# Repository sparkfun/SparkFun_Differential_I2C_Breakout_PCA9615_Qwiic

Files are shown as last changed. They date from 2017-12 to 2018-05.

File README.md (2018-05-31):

SparkFun Differential I2C Breakout - PCA9615 (Qwiic)
========================================

SparkFun Differential I2C Breakout - PCA9615 (Qwiic) (https://cdn.sparkfun.com/assets/parts/1/2/7/4/5/14589-SparkFun_Differential_I2C_Breakout_-_PCA9615__Qwiic_-01.jpg)

[*SparkFun Differential I2C Breakout - PCA9615 (Qwiic) (BOB-14589)*](https://www.sparkfun.com/products/14589)

The SparkFun Differential I<sup>2</sup>C Breakout is the fastest and easiest way to extend the range of your I<sup>2</sup>C communication bus. The breakout uses NXP’s PCA9615 IC, which converts the two default I<sup>2</sup>C signals into four differential signals, two for SCL and two for SDA. 

Repository Contents
-------------------

* **/Documentation** - Datasheets, additional product information
* **/Hardware** - Eagle design files (.brd, .sch)
* **/Production** - Production panel files (.brd)

Documentation
--------------
* **[Hookup Guide](https://learn.sparkfun.com/tutorials/qwiic-differential-i2c-bus-extender-pca9615-hookup-guide)** - Basic hookup guide for the SparkFun Differential I2C Breakout - PCA9615 (Qwiic).

Product Versions
----------------
* [BOB-14589](https://www.sparkfun.com/products/14589)

License Information
-------------------

This product is _**open source**_! 

Please review the LICENSE.md file for license information. 

If you have any questions or concerns on licensing, please contact techsupport@sparkfun.com.

Distributed as-is; no warranty is given.

- Your friends at SparkFun.

_<COLLABORATION CREDIT>_

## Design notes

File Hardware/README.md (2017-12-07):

SparkFun <PRODUCT NAME> Design Files
=====================================

The .sch and .brd files hare are Eagle CAD schematic and PCB design files from SparkFun Electronics.
A freeware version of Eagle can be found [here](http://www.cadsoftusa.com/download-eagle/freeware/).

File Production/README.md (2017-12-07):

SparkFun <PRODUCT NAME> Production Files
=========================================

These are the production files SparkFun uses for printing PCBs.

License Information
-------------------
This product is open source! 

The hardware is released under [Creative Commons ShareAlike 4.0 International](https://creativecommons.org/licenses/by-sa/4.0/).

Please use, reuse, and modify these files as you see fit. Please maintain attribution to SparkFun Electronics and release anything derivative under the same license.

Distributed as-is; no warranty is given.

- Your friends at SparkFun.

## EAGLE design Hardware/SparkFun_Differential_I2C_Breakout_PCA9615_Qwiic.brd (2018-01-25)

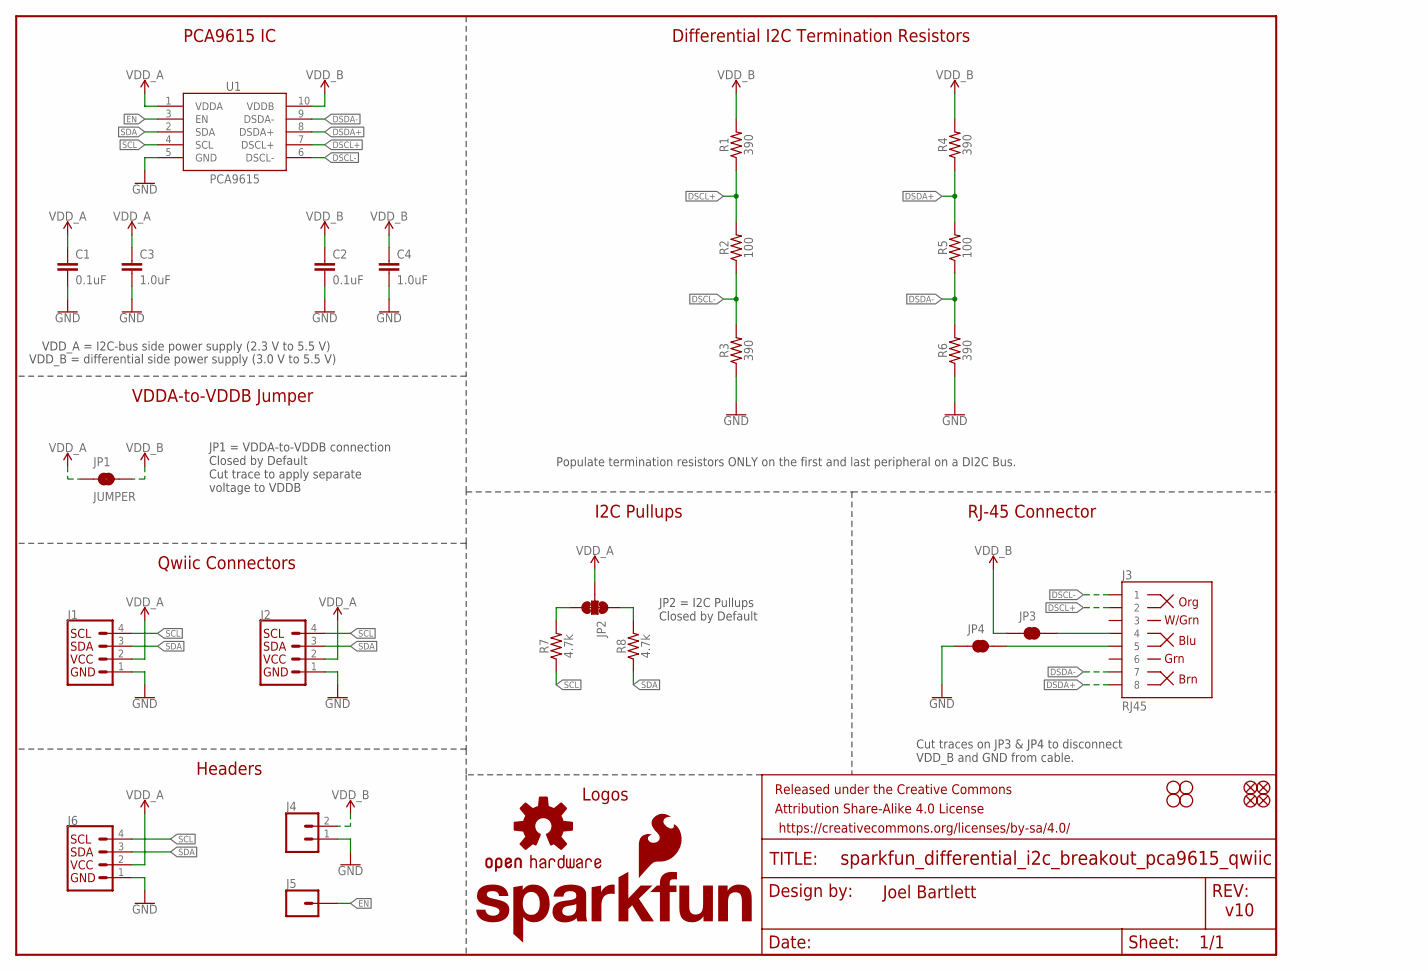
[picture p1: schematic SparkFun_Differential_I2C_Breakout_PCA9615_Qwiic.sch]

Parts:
C1, C2: 0.1uF; 0603
C3, C4: 1.0uF; 0603
FD1, FD2, FD3, FD4: FIDUCIALUFIDUCIAL; FIDUCIAL-MICRO
FRAME1: FRAME-LETTER; CREATIVE_COMMONS
H1, H2, H3, H4: STAND-OFF
J1, J2: QWIIC_CONNECTORJS-1MM; 1X04_1MM_RA
J3: RJ45; RJ45-8
J4: CONN_021X02_NO_SILK; 1X02_NO_SILK
J5: CONN_01PTH_NO_SILK_YES_STOP; 1X01_NO_SILK
J6: I2C_STANDARD_NO_SILK; 1X04_NO_SILK
JP1: JUMPER; SMT-JUMPER_2_NC_TRACE_SILK
JP2: JUMPER-SMT_3_2-NC_TRACE_SILK; SMT-JUMPER_3_2-NC_TRACE_SILK
JP3, JP4: JUMPER-SMT_2_NC_TRACE_SILK; SMT-JUMPER_2_NC_TRACE_SILK
LOGO1: OSHW-LOGOM; OSHW-LOGO-M
LOGO5: SFE_LOGO_NAME_FLAME.1_INCH; SFE_LOGO_NAME_FLAME_.1
R1, R3, R4, R6: 390; 0603
R2, R5: 100; 0603
R7, R8: 4.7k; 0603
U1: PCA9615; TSSOP10

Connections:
DSCL+: J3.2, R1.1, R2.2, U1.7 (DSCL+)
DSCL-: J3.1, R2.1, R3.2, U1.6 (DSCL-)
DSDA+: J3.8, R4.1, R5.2, U1.8 (DSDA+)
DSDA-: J3.7, R5.1, R6.2, U1.9 (DSDA-)
EN: J5.1, U1.3 (EN)
GND: C1.2, C2.2, C3.2, C4.2, J1.1, J2.1, J4.1, J6.1 (GND), JP4.1, R3.1, R6.1, U1.5 (GND)
unnamed: J3.4, JP3.2
unnamed: J3.5, JP4.2
unnamed: JP2.1, R8.2
unnamed: JP2.3, R7.2
SCL: J1.4, J2.4, J6.4 (SCL), R7.1, U1.4 (SCL)
SDA: J1.3, J2.3, J6.3 (SDA), R8.1, U1.2 (SDA)
VDD_A: C1.1, C3.1, J1.2, J2.2, J6.2 (VCC), JP1.1, JP2.2, U1.1 (VDDA)
VDD_B: C2.1, C4.1, J4.2, JP1.2, JP3.1, R1.2, R4.2, U1.10 (VDDB)

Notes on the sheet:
Joel Bartlett
VDDA-to-VDDB Jumper
PCA9615 IC
Qwiic Connectors
v10
JP2 = I2C Pullups Closed by Default
Headers
JP1 = VDDA-to-VDDB connection Closed by Default Cut trace to apply separate voltage to VDDB
I2C Pullups
RJ-45 Connector
Logos
Differential I2C Termination Resistors
Populate termination resistors ONLY on the first and last peripheral on a DI2C Bus.
VDD_A = I2C-bus side power supply (2.3 V to 5.5 V)
VDD_B = differential side power supply (3.0 V to 5.5 V)
Cut traces on JP3 & JP4 to disconnect VDD_B and GND from cable.

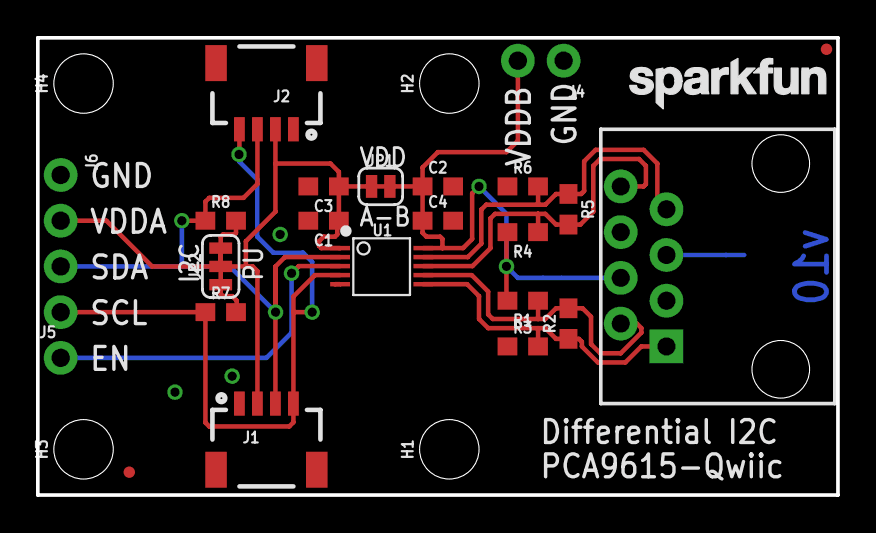
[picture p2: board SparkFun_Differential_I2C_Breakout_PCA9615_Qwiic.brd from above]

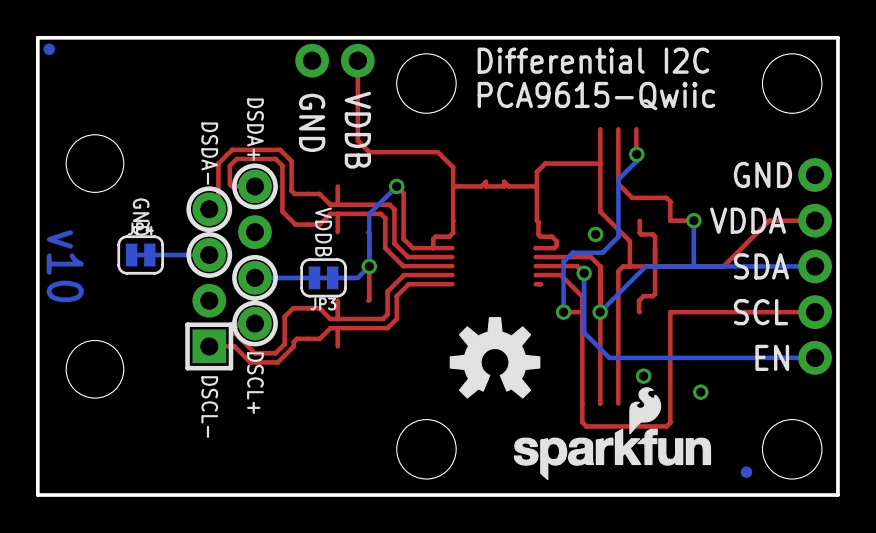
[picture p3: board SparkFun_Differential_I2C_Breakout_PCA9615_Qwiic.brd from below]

Board: 2 copper layers, 44.5 x 25.4 mm, 35 parts (6 on the bottom side), 14 nets.

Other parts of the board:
LOGO3: SFE_LOGO_NAME.1_INCH; SFE_LOGO_NAME_.1

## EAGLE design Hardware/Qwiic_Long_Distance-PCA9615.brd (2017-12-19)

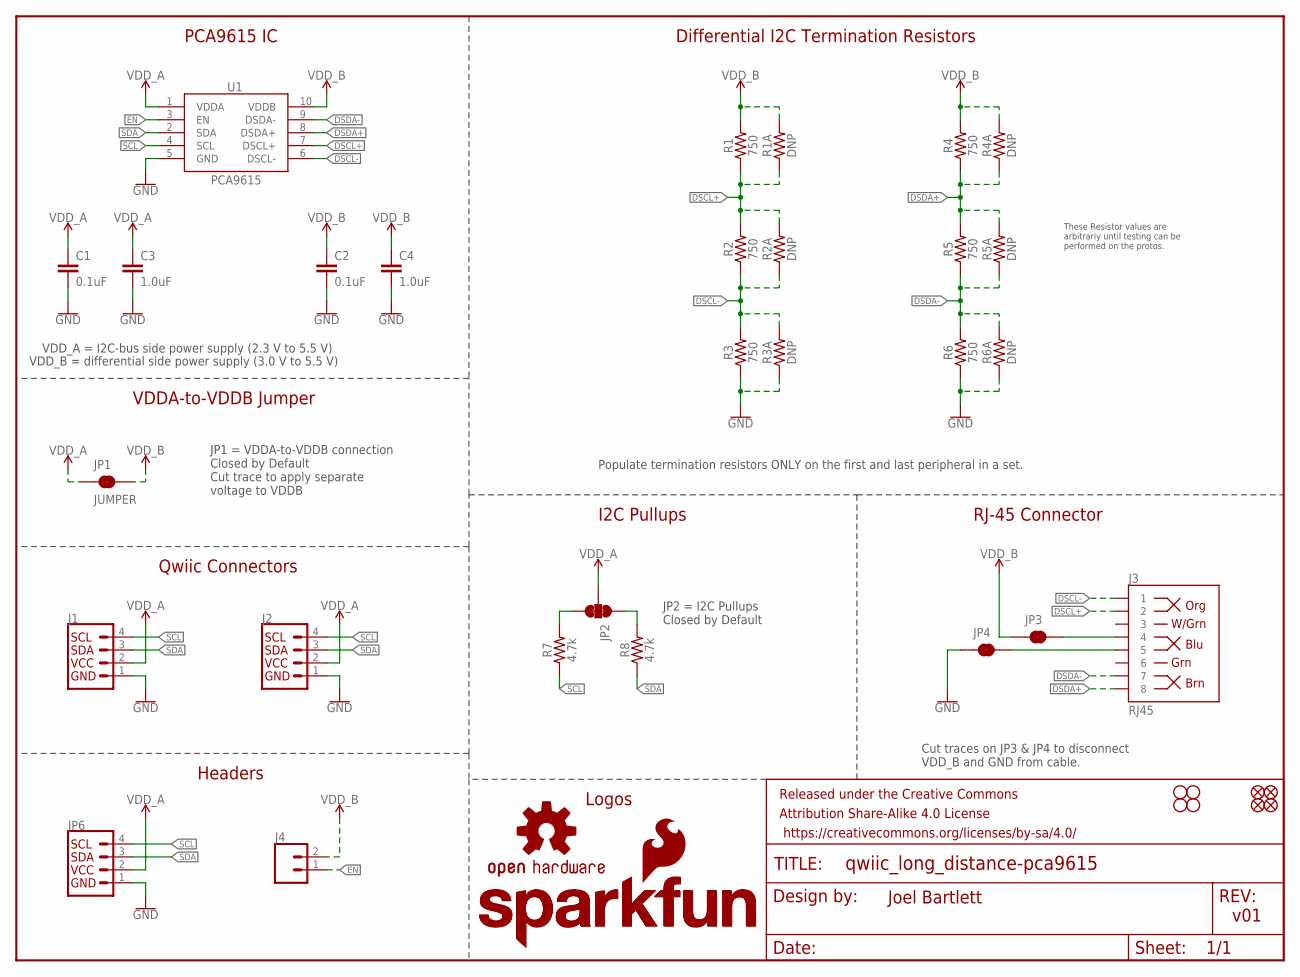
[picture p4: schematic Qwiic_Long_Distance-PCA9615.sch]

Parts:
C1, C2: 0.1uF; 0603
C3, C4: 1.0uF; 0603
FD1, FD2, FD3, FD4: FIDUCIALUFIDUCIAL; FIDUCIAL-MICRO
FRAME1: FRAME-LETTER; CREATIVE_COMMONS
H1, H2, H3, H4: STAND-OFF
J1, J2: QWIIC_CONNECTORJS-1MM; 1X04_1MM_RA
J3: RJ45; RJ45-8
J4: CONN_02; 1X02
JP1: JUMPER; SMT-JUMPER_2_NC_TRACE_SILK
JP2: JUMPER-SMT_3_2-NC_TRACE_SILK; SMT-JUMPER_3_2-NC_TRACE_SILK
JP3, JP4: JUMPER-SMT_2_NC_TRACE_SILK; SMT-JUMPER_2_NC_TRACE_SILK
JP6: I2C_STANDARDSILK; 1X04
LOGO1: OSHW-LOGOM; OSHW-LOGO-M
LOGO2: SFE_LOGO_NAME.1_INCH; SFE_LOGO_NAME_.1
LOGO5: SFE_LOGO_NAME_FLAME.1_INCH; SFE_LOGO_NAME_FLAME_.1
R1, R2, R3, R4, R5, R6: 750; 0603
R1A, R2A, R3A, R4A, R5A, R6A: DNP; AXIAL-0.3
R7, R8: 4.7k; 0603
U1: PCA9615; TSSOP10

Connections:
DSCL+: J3.2, R1.1, R1A.P$1 (1), R2.2, R2A.P$2 (2), U1.7 (DSCL+)
DSCL-: J3.1, R2.1, R2A.P$1 (1), R3.2, R3A.P$2 (2), U1.6 (DSCL-)
DSDA+: J3.8, R4.1, R4A.P$1 (1), R5.2, R5A.P$2 (2), U1.8 (DSDA+)
DSDA-: J3.7, R5.1, R5A.P$1 (1), R6.2, R6A.P$2 (2), U1.9 (DSDA-)
EN: J4.1, U1.3 (EN)
GND: C1.2, C2.2, C3.2, C4.2, J1.1, J2.1, JP4.1, JP6.1 (GND), R3.1, R3A.P$1 (1), R6.1, R6A.P$1 (1), U1.5 (GND)
unnamed: J3.4, JP3.2
unnamed: J3.5, JP4.2
unnamed: JP2.1, R8.2
unnamed: JP2.3, R7.2
SCL: J1.4, J2.4, JP6.4 (SCL), R7.1, U1.4 (SCL)
SDA: J1.3, J2.3, JP6.3 (SDA), R8.1, U1.2 (SDA)
VDD_A: C1.1, C3.1, J1.2, J2.2, JP1.1, JP2.2, JP6.2 (VCC), U1.1 (VDDA)
VDD_B: C2.1, C4.1, J4.2, JP1.2, JP3.1, R1.2, R1A.P$2 (2), R4.2, R4A.P$2 (2), U1.10 (VDDB)

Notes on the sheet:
Joel Bartlett
VDDA-to-VDDB Jumper
PCA9615 IC
Qwiic Connectors
v01
JP2 = I2C Pullups Closed by Default
Headers
JP1 = VDDA-to-VDDB connection Closed by Default Cut trace to apply separate voltage to VDDB
I2C Pullups
RJ-45 Connector
Logos
Differential I2C Termination Resistors
Populate termination resistors ONLY on the first and last peripheral in a set.
These Resistor values are arbitrariy until testing can be performed on the protos.
VDD_A = I2C-bus side power supply (2.3 V to 5.5 V)
VDD_B = differential side power supply (3.0 V to 5.5 V)
Cut traces on JP3 & JP4 to disconnect VDD_B and GND from cable.

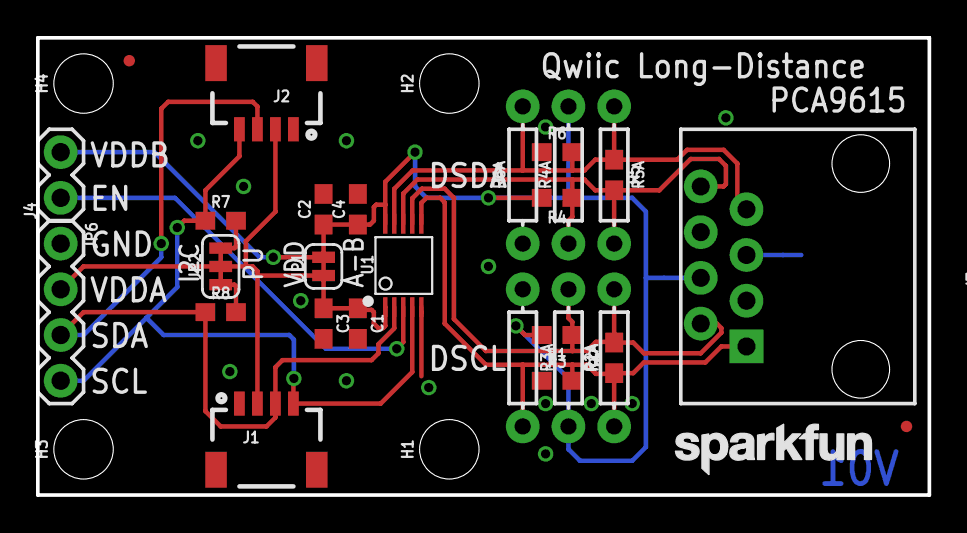
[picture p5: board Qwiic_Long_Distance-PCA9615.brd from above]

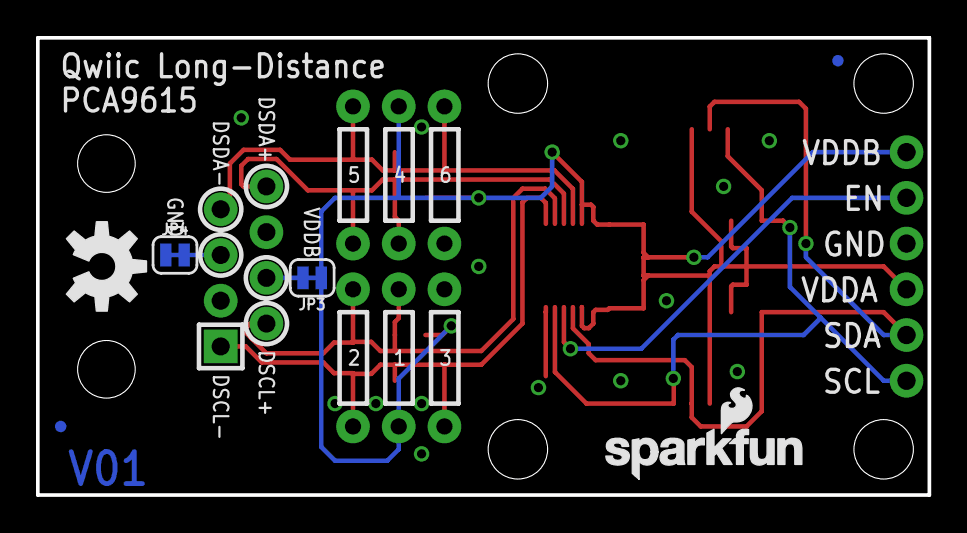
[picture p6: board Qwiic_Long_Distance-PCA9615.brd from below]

Board: 2 copper layers, 49.5 x 25.4 mm, 40 parts (6 on the bottom side), 14 nets.

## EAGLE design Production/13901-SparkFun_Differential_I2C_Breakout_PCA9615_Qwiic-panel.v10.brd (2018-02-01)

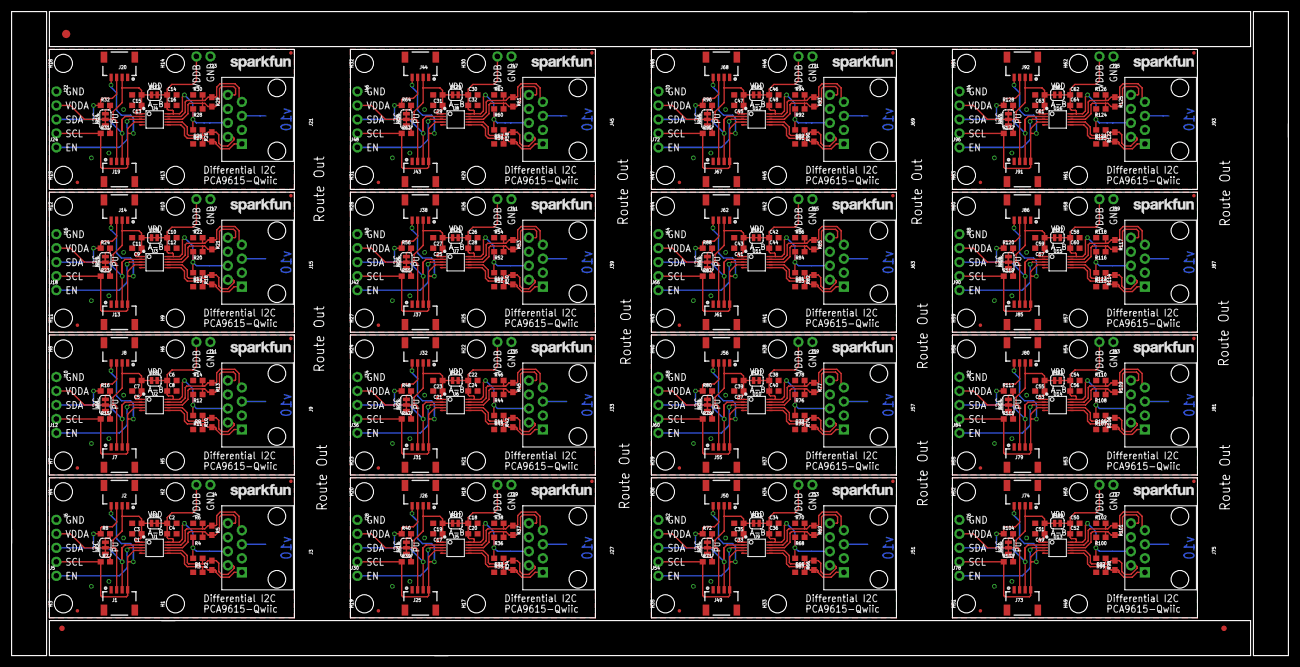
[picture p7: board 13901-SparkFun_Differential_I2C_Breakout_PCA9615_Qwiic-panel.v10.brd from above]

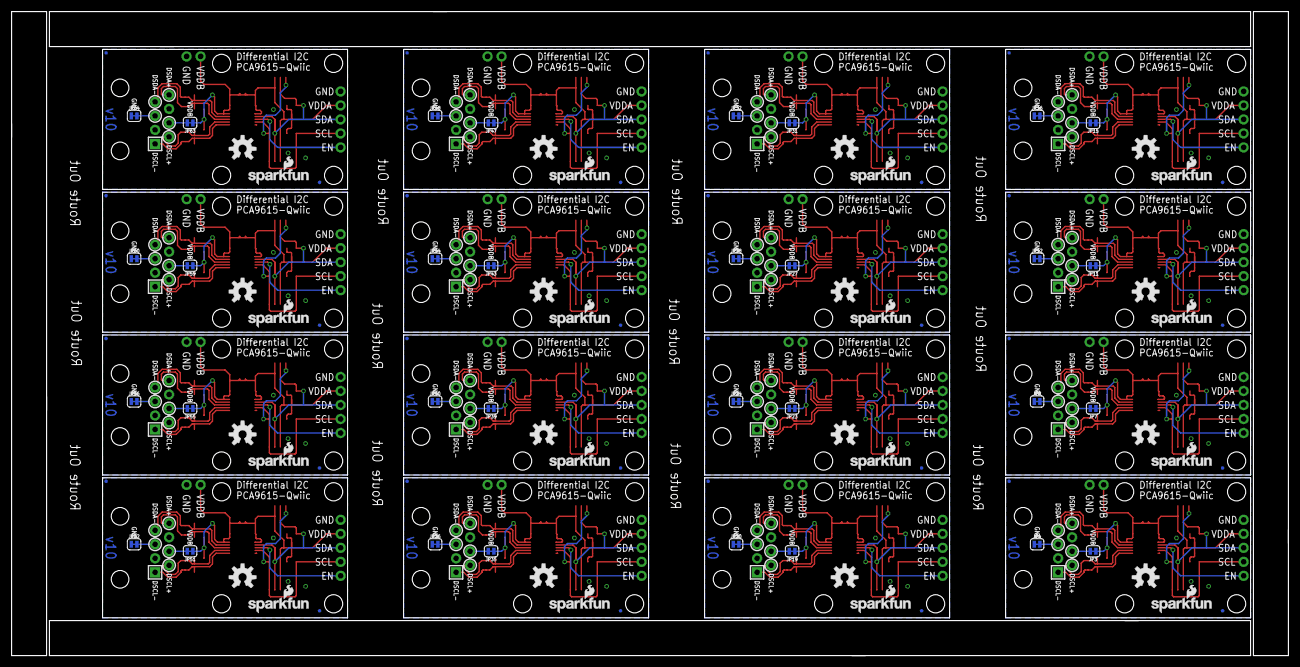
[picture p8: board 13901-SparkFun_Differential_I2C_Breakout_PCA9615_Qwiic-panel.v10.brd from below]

Board: 2 copper layers, 231.6 x 116.8 mm, 547 parts (96 on the bottom side), 224 nets.

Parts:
C1, C2, C5, C6, C9, C10, C13, C14, C17, C18, C21, C22, C25, C26, C29, C30, C33, C34, C37, C38, C41, C42, C45, C46, C49, C50, C53, C54, C57, C58, C61, C62: 0.1uF; 0603
C3, C4, C7, C8, C11, C12, C15, C16, C19, C20, C23, C24, C27, C28, C31, C32, C35, C36, C39, C40, C43, C44, C47, C48, C51, C52, C55, C56, C59, C60, C63, C64: 1.0uF; 0603
E$1, E$2: FIDUCIAL-1X2
E$3: FIDUCIAL-1.5X3
FD1, FD2, FD3, FD4, FD5, FD6, FD7, FD8, FD9, FD10, FD11, FD12, FD13, FD14, FD15, FD16, FD17, FD18, FD19, FD20, FD21, FD22, FD23, FD24, FD25, FD26, FD27, FD28, FD29, FD30, FD31, FD32, FD33, FD34, FD35, FD36, FD37, FD38, FD39, FD40, FD41, FD42, FD43, FD44, FD45, FD46, FD47, FD48, FD49, FD50, FD51, FD52, FD53, FD54, FD55, FD56, FD57, FD58, FD59, FD60, FD61, FD62, FD63, FD64: FIDUCIALUFIDUCIAL; FIDUCIAL-MICRO
H1, H2, H3, H4, H5, H6, H7, H8, H9, H10, H11, H12, H13, H14, H15, H16, H17, H18, H19, H20, H21, H22, H23, H24, H25, H26, H27, H28, H29, H30, H31, H32, H33, H34, H35, H36, H37, H38, H39, H40, H41, H42, H43, H44, H45, H46, H47, H48, H49, H50, H51, H52, H53, H54, H55, H56, H57, H58, H59, H60, H61, H62, H63, H64: STAND-OFF
J1, J2, J7, J8, J13, J14, J19, J20, J25, J26, J31, J32, J37, J38, J43, J44, J49, J50, J55, J56, J61, J62, J67, J68, J73, J74, J79, J80, J85, J86, J91, J92: 1X04_1MM_RA
J3, J9, J15, J21, J27, J33, J39, J45, J51, J57, J63, J69, J75, J81, J87, J93: RJ45; RJ45-8
J4, J11, J17, J23, J29, J35, J41, J47, J53, J59, J65, J71, J77, J83, J89, J95: 1X02_NO_SILK
J5, J12, J18, J24, J30, J36, J42, J48, J54, J60, J66, J72, J78, J84, J90, J96: 1X01_NO_SILK
J6, J10, J16, J22, J28, J34, J40, J46, J52, J58, J64, J70, J76, J82, J88, J94: 1X04_NO_SILK
JP1, JP5, JP9, JP13, JP17, JP21, JP25, JP29, JP33, JP37, JP41, JP45, JP49, JP53, JP57, JP61: JUMPER; SMT-JUMPER_2_NC_TRACE_SILK
JP2, JP6, JP10, JP14, JP18, JP22, JP26, JP30, JP34, JP38, JP42, JP46, JP50, JP54, JP58, JP62: SMT-JUMPER_3_2-NC_TRACE_SILK
JP3, JP4, JP7, JP8, JP11, JP12, JP15, JP16, JP19, JP20, JP23, JP24, JP27, JP28, JP31, JP32, JP35, JP36, JP39, JP40, JP43, JP44, JP47, JP48, JP51, JP52, JP55, JP56, JP59, JP60, JP63, JP64: SMT-JUMPER_2_NC_TRACE_SILK
LOGO1, LOGO2, LOGO7, LOGO10, LOGO13, LOGO16, LOGO19, LOGO22, LOGO25, LOGO28, LOGO31, LOGO34, LOGO37, LOGO40, LOGO43, LOGO46: OSHW-LOGOM; OSHW-LOGO-M
LOGO3, LOGO6, LOGO9, LOGO12, LOGO15, LOGO18, LOGO21, LOGO24, LOGO27, LOGO30, LOGO33, LOGO36, LOGO39, LOGO42, LOGO45, LOGO48: SFE_LOGO_NAME.1_INCH; SFE_LOGO_NAME_.1
LOGO4, LOGO5, LOGO8, LOGO11, LOGO14, LOGO17, LOGO20, LOGO23, LOGO26, LOGO29, LOGO32, LOGO35, LOGO38, LOGO41, LOGO44, LOGO47: SFE_LOGO_NAME_FLAME.1_INCH; SFE_LOGO_NAME_FLAME_.1
R1, R3, R4, R6, R9, R11, R12, R14, R17, R19, R20, R22, R25, R27, R28, R30, R33, R35, R36, R38, R41, R43, R44, R46, R49, R51, R52, R54, R57, R59, R60, R62, R65, R67, R68, R70, R73, R75, R76, R78, R81, R83, R84, R86, R89, R91, R92, R94, R97, R99, R100, R102, R105, R107, R108, R110, R113, R115, R116, R118, R121, R123, R124, R126: 390; 0603
R2, R5, R10, R13, R18, R21, R26, R29, R34, R37, R42, R45, R50, R53, R58, R61, R66, R69, R74, R77, R82, R85, R90, R93, R98, R101, R106, R109, R114, R117, R122, R125: 100; 0603
R7, R8, R15, R16, R23, R24, R31, R32, R39, R40, R47, R48, R55, R56, R63, R64, R71, R72, R79, R80, R87, R88, R95, R96, R103, R104, R111, R112, R119, R120, R127, R128: 4.7k; 0603
U1, U2, U3, U4, U5, U6, U7, U8, U9, U10, U11, U12, U13, U14, U15, U16: PCA9615; TSSOP10

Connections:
DSCL+: J3.2, R1.1, R2.2, U1.7
DSCL+1: J9.2, R9.1, R10.2, U2.7
DSCL+2: J15.2, R17.1, R18.2, U3.7
DSCL+3: J21.2, R25.1, R26.2, U4.7
DSCL+4: J27.2, R33.1, R34.2, U5.7
DSCL+5: J33.2, R41.1, R42.2, U6.7
DSCL+6: J39.2, R49.1, R50.2, U7.7
DSCL+7: J45.2, R57.1, R58.2, U8.7
DSCL+8: J51.2, R65.1, R66.2, U9.7
DSCL+9: J57.2, R73.1, R74.2, U10.7
DSCL+10: J63.2, R81.1, R82.2, U11.7
DSCL+11: J69.2, R89.1, R90.2, U12.7
DSCL+12: J75.2, R97.1, R98.2, U13.7
DSCL+13: J81.2, R105.1, R106.2, U14.7
DSCL+14: J87.2, R113.1, R114.2, U15.7
DSCL+15: J93.2, R121.1, R122.2, U16.7
DSCL-: J3.1, R2.1, R3.2, U1.6
DSCL-1: J9.1, R10.1, R11.2, U2.6
DSCL-2: J15.1, R18.1, R19.2, U3.6
DSCL-3: J21.1, R26.1, R27.2, U4.6
DSCL-4: J27.1, R34.1, R35.2, U5.6
DSCL-5: J33.1, R42.1, R43.2, U6.6
DSCL-6: J39.1, R50.1, R51.2, U7.6
DSCL-7: J45.1, R58.1, R59.2, U8.6
DSCL-8: J51.1, R66.1, R67.2, U9.6
DSCL-9: J57.1, R74.1, R75.2, U10.6
DSCL-10: J63.1, R82.1, R83.2, U11.6
DSCL-11: J69.1, R90.1, R91.2, U12.6
DSCL-12: J75.1, R98.1, R99.2, U13.6
DSCL-13: J81.1, R106.1, R107.2, U14.6
DSCL-14: J87.1, R114.1, R115.2, U15.6
DSCL-15: J93.1, R122.1, R123.2, U16.6
DSDA+: J3.8, R4.1, R5.2, U1.8
DSDA+1: J9.8, R12.1, R13.2, U2.8
DSDA+2: J15.8, R20.1, R21.2, U3.8
DSDA+3: J21.8, R28.1, R29.2, U4.8
DSDA+4: J27.8, R36.1, R37.2, U5.8
DSDA+5: J33.8, R44.1, R45.2, U6.8
DSDA+6: J39.8, R52.1, R53.2, U7.8
DSDA+7: J45.8, R60.1, R61.2, U8.8
DSDA+8: J51.8, R68.1, R69.2, U9.8
DSDA+9: J57.8, R76.1, R77.2, U10.8
DSDA+10: J63.8, R84.1, R85.2, U11.8
DSDA+11: J69.8, R92.1, R93.2, U12.8
DSDA+12: J75.8, R100.1, R101.2, U13.8
DSDA+13: J81.8, R108.1, R109.2, U14.8
DSDA+14: J87.8, R116.1, R117.2, U15.8
DSDA+15: J93.8, R124.1, R125.2, U16.8
DSDA-: J3.7, R5.1, R6.2, U1.9
DSDA-1: J9.7, R13.1, R14.2, U2.9
DSDA-2: J15.7, R21.1, R22.2, U3.9
DSDA-3: J21.7, R29.1, R30.2, U4.9
DSDA-4: J27.7, R37.1, R38.2, U5.9
DSDA-5: J33.7, R45.1, R46.2, U6.9
DSDA-6: J39.7, R53.1, R54.2, U7.9
DSDA-7: J45.7, R61.1, R62.2, U8.9
DSDA-8: J51.7, R69.1, R70.2, U9.9
DSDA-9: J57.7, R77.1, R78.2, U10.9
DSDA-10: J63.7, R85.1, R86.2, U11.9
DSDA-11: J69.7, R93.1, R94.2, U12.9
DSDA-12: J75.7, R101.1, R102.2, U13.9
DSDA-13: J81.7, R109.1, R110.2, U14.9
DSDA-14: J87.7, R117.1, R118.2, U15.9
DSDA-15: J93.7, R125.1, R126.2, U16.9
EN: J5.1, U1.3
EN1: J12.1, U2.3
EN2: J18.1, U3.3
EN3: J24.1, U4.3
EN4: J30.1, U5.3
EN5: J36.1, U6.3
EN6: J42.1, U7.3
EN7: J48.1, U8.3
EN8: J54.1, U9.3
EN9: J60.1, U10.3
EN10: J66.1, U11.3
EN11: J72.1, U12.3
EN12: J78.1, U13.3
EN13: J84.1, U14.3
EN14: J90.1, U15.3
EN15: J96.1, U16.3
GND: C1.2, C2.2, C3.2, C4.2, J1.1, J2.1, J4.1, J6.1, JP4.1, R3.1, R6.1, U1.5
GND1: C5.2, C6.2, C7.2, C8.2, J7.1, J8.1, J10.1, J11.1, JP8.1, R11.1, R14.1, U2.5
GND2: C9.2, C10.2, C11.2, C12.2, J13.1, J14.1, J16.1, J17.1, JP12.1, R19.1, R22.1, U3.5
GND3: C13.2, C14.2, C15.2, C16.2, J19.1, J20.1, J22.1, J23.1, JP16.1, R27.1, R30.1, U4.5
GND4: C17.2, C18.2, C19.2, C20.2, J25.1, J26.1, J28.1, J29.1, JP20.1, R35.1, R38.1, U5.5
GND5: C21.2, C22.2, C23.2, C24.2, J31.1, J32.1, J34.1, J35.1, JP24.1, R43.1, R46.1, U6.5
GND6: C25.2, C26.2, C27.2, C28.2, J37.1, J38.1, J40.1, J41.1, JP28.1, R51.1, R54.1, U7.5
GND7: C29.2, C30.2, C31.2, C32.2, J43.1, J44.1, J46.1, J47.1, JP32.1, R59.1, R62.1, U8.5
GND8: C33.2, C34.2, C35.2, C36.2, J49.1, J50.1, J52.1, J53.1, JP36.1, R67.1, R70.1, U9.5
GND9: C37.2, C38.2, C39.2, C40.2, J55.1, J56.1, J58.1, J59.1, JP40.1, R75.1, R78.1, U10.5
GND10: C41.2, C42.2, C43.2, C44.2, J61.1, J62.1, J64.1, J65.1, JP44.1, R83.1, R86.1, U11.5
GND11: C45.2, C46.2, C47.2, C48.2, J67.1, J68.1, J70.1, J71.1, JP48.1, R91.1, R94.1, U12.5
GND12: C49.2, C50.2, C51.2, C52.2, J73.1, J74.1, J76.1, J77.1, JP52.1, R99.1, R102.1, U13.5
GND13: C53.2, C54.2, C55.2, C56.2, J79.1, J80.1, J82.1, J83.1, JP56.1, R107.1, R110.1, U14.5
GND14: C57.2, C58.2, C59.2, C60.2, J85.1, J86.1, J88.1, J89.1, JP60.1, R115.1, R118.1, U15.5
GND15: C61.2, C62.2, C63.2, C64.2, J91.1, J92.1, J94.1, J95.1, JP64.1, R123.1, R126.1, U16.5
unnamed: J3.4, JP3.2
unnamed: J3.5, JP4.2
unnamed: JP2.1, R8.2
unnamed: JP2.3, R7.2
unnamed: JP6.1, R16.2
unnamed: JP6.3, R15.2
unnamed: J9.4, JP7.2
unnamed: J9.5, JP8.2
unnamed: JP10.1, R24.2
unnamed: JP10.3, R23.2
unnamed: J15.4, JP11.2
unnamed: J15.5, JP12.2
unnamed: JP14.1, R32.2
unnamed: JP14.3, R31.2
unnamed: J21.4, JP15.2
unnamed: J21.5, JP16.2
unnamed: JP18.1, R40.2
unnamed: JP18.3, R39.2
unnamed: J27.4, JP19.2
unnamed: J27.5, JP20.2
unnamed: JP22.1, R48.2
unnamed: JP22.3, R47.2
unnamed: J33.4, JP23.2
unnamed: J33.5, JP24.2
unnamed: JP26.1, R56.2
unnamed: JP26.3, R55.2
unnamed: J39.4, JP27.2
unnamed: J39.5, JP28.2
unnamed: JP30.1, R64.2
unnamed: JP30.3, R63.2
unnamed: J45.4, JP31.2
unnamed: J45.5, JP32.2
unnamed: JP34.1, R72.2
unnamed: JP34.3, R71.2
unnamed: J51.4, JP35.2
unnamed: J51.5, JP36.2
unnamed: JP38.1, R80.2
unnamed: JP38.3, R79.2
unnamed: J57.4, JP39.2
unnamed: J57.5, JP40.2
unnamed: JP42.1, R88.2
unnamed: JP42.3, R87.2
unnamed: J63.4, JP43.2
unnamed: J63.5, JP44.2
unnamed: JP46.1, R96.2
unnamed: JP46.3, R95.2
unnamed: J69.4, JP47.2
unnamed: J69.5, JP48.2
unnamed: JP50.1, R104.2
unnamed: JP50.3, R103.2
unnamed: J75.4, JP51.2
unnamed: J75.5, JP52.2
unnamed: JP54.1, R112.2
unnamed: JP54.3, R111.2
unnamed: J81.4, JP55.2
unnamed: J81.5, JP56.2
unnamed: JP58.1, R120.2
unnamed: JP58.3, R119.2
unnamed: J87.4, JP59.2
unnamed: J87.5, JP60.2
unnamed: JP62.1, R128.2
unnamed: JP62.3, R127.2
unnamed: J93.4, JP63.2
unnamed: J93.5, JP64.2
SCL: J1.4, J2.4, J6.4, R7.1, U1.4
SCL1: J7.4, J8.4, J10.4, R15.1, U2.4
SCL2: J13.4, J14.4, J16.4, R23.1, U3.4
SCL3: J19.4, J20.4, J22.4, R31.1, U4.4
SCL4: J25.4, J26.4, J28.4, R39.1, U5.4
SCL5: J31.4, J32.4, J34.4, R47.1, U6.4
SCL6: J37.4, J38.4, J40.4, R55.1, U7.4
SCL7: J43.4, J44.4, J46.4, R63.1, U8.4
SCL8: J49.4, J50.4, J52.4, R71.1, U9.4
SCL9: J55.4, J56.4, J58.4, R79.1, U10.4
SCL10: J61.4, J62.4, J64.4, R87.1, U11.4
SCL11: J67.4, J68.4, J70.4, R95.1, U12.4
SCL12: J73.4, J74.4, J76.4, R103.1, U13.4
SCL13: J79.4, J80.4, J82.4, R111.1, U14.4
SCL14: J85.4, J86.4, J88.4, R119.1, U15.4
SCL15: J91.4, J92.4, J94.4, R127.1, U16.4
SDA: J1.3, J2.3, J6.3, R8.1, U1.2
SDA1: J7.3, J8.3, J10.3, R16.1, U2.2
SDA2: J13.3, J14.3, J16.3, R24.1, U3.2
SDA3: J19.3, J20.3, J22.3, R32.1, U4.2
SDA4: J25.3, J26.3, J28.3, R40.1, U5.2
SDA5: J31.3, J32.3, J34.3, R48.1, U6.2
SDA6: J37.3, J38.3, J40.3, R56.1, U7.2
SDA7: J43.3, J44.3, J46.3, R64.1, U8.2
SDA8: J49.3, J50.3, J52.3, R72.1, U9.2
SDA9: J55.3, J56.3, J58.3, R80.1, U10.2
SDA10: J61.3, J62.3, J64.3, R88.1, U11.2
SDA11: J67.3, J68.3, J70.3, R96.1, U12.2
SDA12: J73.3, J74.3, J76.3, R104.1, U13.2
SDA13: J79.3, J80.3, J82.3, R112.1, U14.2
SDA14: J85.3, J86.3, J88.3, R120.1, U15.2
SDA15: J91.3, J92.3, J94.3, R128.1, U16.2
VDD_A: C1.1, C3.1, J1.2, J2.2, J6.2, JP1.1, JP2.2, U1.1
VDD_A1: C5.1, C7.1, J7.2, J8.2, J10.2, JP5.1, JP6.2, U2.1
VDD_A2: C9.1, C11.1, J13.2, J14.2, J16.2, JP9.1, JP10.2, U3.1
VDD_A3: C13.1, C15.1, J19.2, J20.2, J22.2, JP13.1, JP14.2, U4.1
VDD_A4: C17.1, C19.1, J25.2, J26.2, J28.2, JP17.1, JP18.2, U5.1
VDD_A5: C21.1, C23.1, J31.2, J32.2, J34.2, JP21.1, JP22.2, U6.1
VDD_A6: C25.1, C27.1, J37.2, J38.2, J40.2, JP25.1, JP26.2, U7.1
VDD_A7: C29.1, C31.1, J43.2, J44.2, J46.2, JP29.1, JP30.2, U8.1
VDD_A8: C33.1, C35.1, J49.2, J50.2, J52.2, JP33.1, JP34.2, U9.1
VDD_A9: C37.1, C39.1, J55.2, J56.2, J58.2, JP37.1, JP38.2, U10.1
VDD_A10: C41.1, C43.1, J61.2, J62.2, J64.2, JP41.1, JP42.2, U11.1
VDD_A11: C45.1, C47.1, J67.2, J68.2, J70.2, JP45.1, JP46.2, U12.1
VDD_A12: C49.1, C51.1, J73.2, J74.2, J76.2, JP49.1, JP50.2, U13.1
VDD_A13: C53.1, C55.1, J79.2, J80.2, J82.2, JP53.1, JP54.2, U14.1
VDD_A14: C57.1, C59.1, J85.2, J86.2, J88.2, JP57.1, JP58.2, U15.1
VDD_A15: C61.1, C63.1, J91.2, J92.2, J94.2, JP61.1, JP62.2, U16.1
VDD_B: C2.1, C4.1, J4.2, JP1.2, JP3.1, R1.2, R4.2, U1.10
VDD_B1: C6.1, C8.1, J11.2, JP5.2, JP7.1, R9.2, R12.2, U2.10
VDD_B2: C10.1, C12.1, J17.2, JP9.2, JP11.1, R17.2, R20.2, U3.10
VDD_B3: C14.1, C16.1, J23.2, JP13.2, JP15.1, R25.2, R28.2, U4.10
VDD_B4: C18.1, C20.1, J29.2, JP17.2, JP19.1, R33.2, R36.2, U5.10
VDD_B5: C22.1, C24.1, J35.2, JP21.2, JP23.1, R41.2, R44.2, U6.10
VDD_B6: C26.1, C28.1, J41.2, JP25.2, JP27.1, R49.2, R52.2, U7.10
VDD_B7: C30.1, C32.1, J47.2, JP29.2, JP31.1, R57.2, R60.2, U8.10
VDD_B8: C34.1, C36.1, J53.2, JP33.2, JP35.1, R65.2, R68.2, U9.10
VDD_B9: C38.1, C40.1, J59.2, JP37.2, JP39.1, R73.2, R76.2, U10.10
VDD_B10: C42.1, C44.1, J65.2, JP41.2, JP43.1, R81.2, R84.2, U11.10
VDD_B11: C46.1, C48.1, J71.2, JP45.2, JP47.1, R89.2, R92.2, U12.10
VDD_B12: C50.1, C52.1, J77.2, JP49.2, JP51.1, R97.2, R100.2, U13.10
VDD_B13: C54.1, C56.1, J83.2, JP53.2, JP55.1, R105.2, R108.2, U14.10
VDD_B14: C58.1, C60.1, J89.2, JP57.2, JP59.1, R113.2, R116.2, U15.10
VDD_B15: C62.1, C64.1, J95.2, JP61.2, JP63.1, R121.2, R124.2, U16.10

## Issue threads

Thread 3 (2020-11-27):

Feature Request: Please add lead out pins for unused ethernet pins

psteininger, 2020-11-27:
It would be super nice to be able to repurpose the 2 unused wires in the ethernet cable to carry interrupt signals from I2C GPIO extenders, or use them for any other purpose.

It's possible to solder onto them now, but it would be superbly more elegant to have 2 pins, say on the opposite side of VDDB and GND leads.

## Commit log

2017-12-07 Initial commit of .brd and .sch files
    [Qwiic_Long_Distance-PCA9615.brd, Qwiic_Long_Distance-PCA9615.sch]
2017-12-11 Updated routing for Differential signals
    [Qwiic_Long_Distance-PCA9615.brd]
2017-12-13 ENG Checklist update
    Changes made after design review and ENG checklist.
    [Qwiic_Long_Distance-PCA9615.brd, Qwiic_Long_Distance-PCA9615.sch]
2017-12-19 Adding minor changes from QC checklist
    [Qwiic_Long_Distance-PCA9615.brd, Qwiic_Long_Distance-PCA9615.sch]
2018-01-23 Pushing design before Redboard Review
    [SparkFun_Differential_I2C_Breakout_PCA9615_Qwiic.brd, SparkFun_Differential_I2C_Breakout_PCA9615_Qwiic.sch]
2018-01-24 Adding PCA9615 to SFE Eagle Library
    [SparkFun_Differential_I2C_Breakout_PCA9615_Qwiic.brd, SparkFun_Differential_I2C_Breakout_PCA9615_Qwiic.sch]
2018-01-25 ENG Design Checklist changes
    [SparkFun_Differential_I2C_Breakout_PCA9615_Qwiic.brd, SparkFun_Differential_I2C_Breakout_PCA9615_Qwiic.sch]
2018-01-25 Ready for REDs
    [SparkFun_Differential_I2C_Breakout_PCA9615_Qwiic.brd]

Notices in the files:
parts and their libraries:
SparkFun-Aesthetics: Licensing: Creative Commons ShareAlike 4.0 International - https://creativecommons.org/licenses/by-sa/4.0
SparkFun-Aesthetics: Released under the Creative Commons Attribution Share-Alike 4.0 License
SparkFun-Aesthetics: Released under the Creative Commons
